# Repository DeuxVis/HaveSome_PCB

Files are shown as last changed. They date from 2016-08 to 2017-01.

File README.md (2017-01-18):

## Intro

This is a breakout board for low pin count SMD components : 0402 0603 0805 1206 SOT23 SOT223 SOT323.

Before that when you wanted to breadboard some SMD components it was a bit tricky :

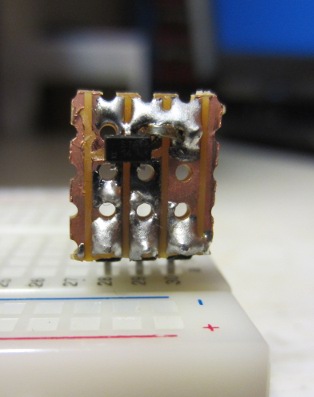
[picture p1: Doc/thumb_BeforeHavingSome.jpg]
Before Before having some...


Now you can use those tiny pretty easy to solder adapters :

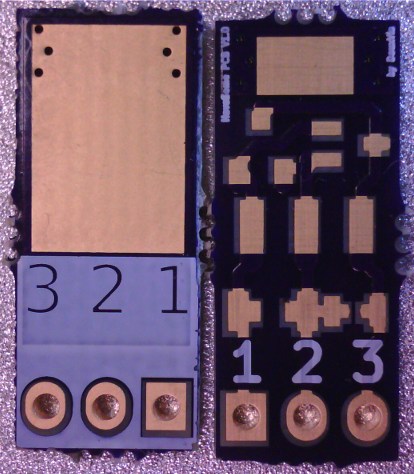
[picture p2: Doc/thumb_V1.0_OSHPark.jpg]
After Ready to prototype !


## Example uses

See some [sample usages](https://hackaday.io/project/10412-hacker-breakout-board-for-most-popular-smd#menu-details)

## Motivation

This breakout board is usefull to prototype with SMD components by allowing to plug those in a breadboard - or any matching 0.1" spaced pins, like some arduino family boards for instance.

It is derived from the [Awesome PCB project](https://hackaday.io/project/10412-hacker-breakout-board-for-most-popular-smd) by Simon.

My motivation for redesigning it from scratch was to :

*   Learn Kicad.
*   Allow people to order those boards for themselves, as Simon did not "yet" release his files.
*   I need to use some of those.

## Documentation

Not much yet, some pictures in the Doc subfolder.
You can probably use some informations in the [pdf from awesomepcb](http://www.awesomepcb.com/wp-content/uploads/2015/06/0603_0805_1206_SOT23_SOT223_0402_SOT323_rev01_documentation-PCB.pdf) although that board is somewhat different.

## Changelog

### V1.1

Status : still untested.

* Trying to let PCBs.io manufacturing process actually produce vias by not burying them under a pad.
* Beefier traces, especially on center pin - thanks to original Awsome PCB designer Simon for the suggestion on hackaday.io.
* Beefier vias for better current/heat transfer.
* Linked pad 2 and 4 of SOT223 for footprint compatible packages which lack the middle pin. 
* Added silkscreen annotations of pads to pins id matching - thanks to warhawk-avg on hackaday.io for the suggestion.

### V1.0

Status : tested and working but might be bugged depending on PCB manufacturer, vias between top and bottom heatsink surface may not be produced.

## License



This work is licensed under a [Creative Commons Attribution-NonCommercial-ShareAlike 3.0 Unported](https://creativecommons.org/licenses/by-nc-sa/3.0/) License - aka CC BY-NC-SA 3.0.

I chose non commercial because the idea is not mine and I don't want someone ripping off sales from [the original publisher](http://www.awesomepcb.com/product-category/pcb-bread-board-tools/).

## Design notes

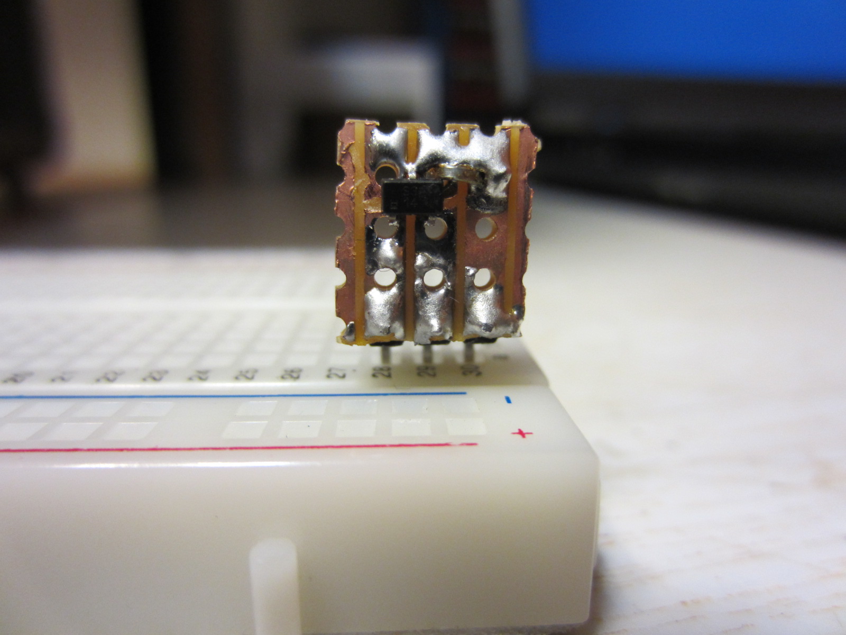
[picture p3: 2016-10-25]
Doc/BeforeHavingSome.jpg

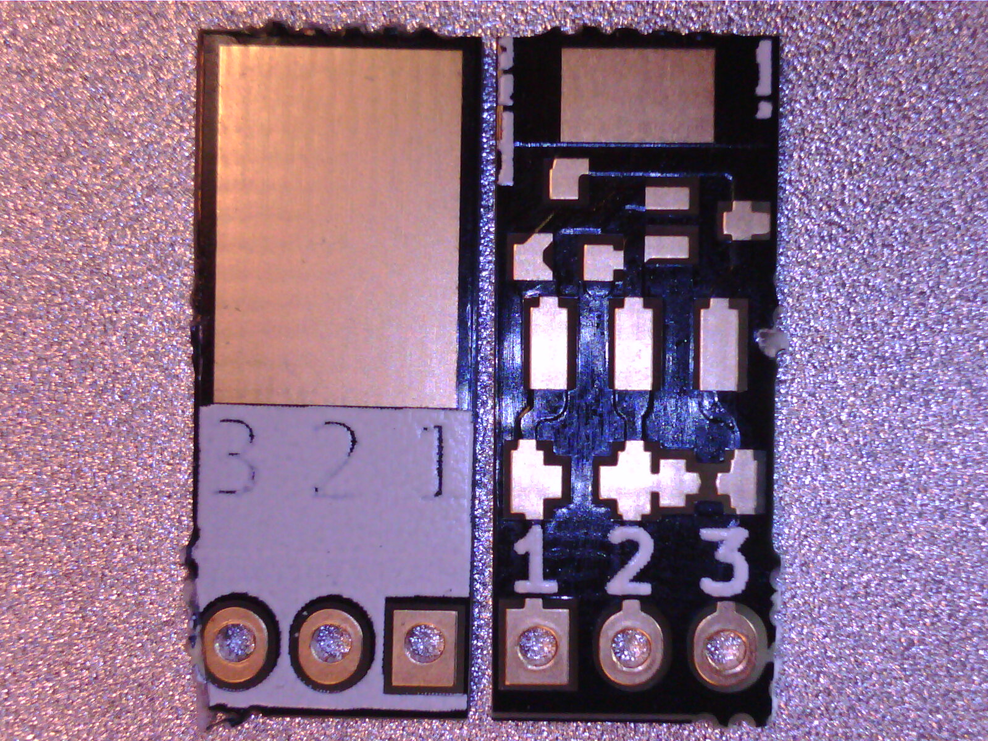
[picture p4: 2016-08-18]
Doc/V1.0_PCBs.io.jpg

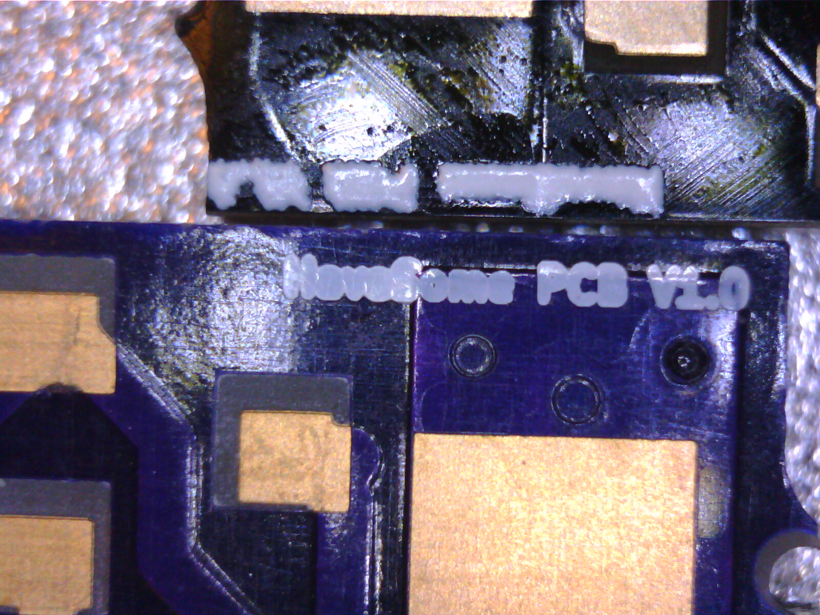
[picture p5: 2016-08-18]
Doc/V1.0_Comparizon_Silkscreen.jpg

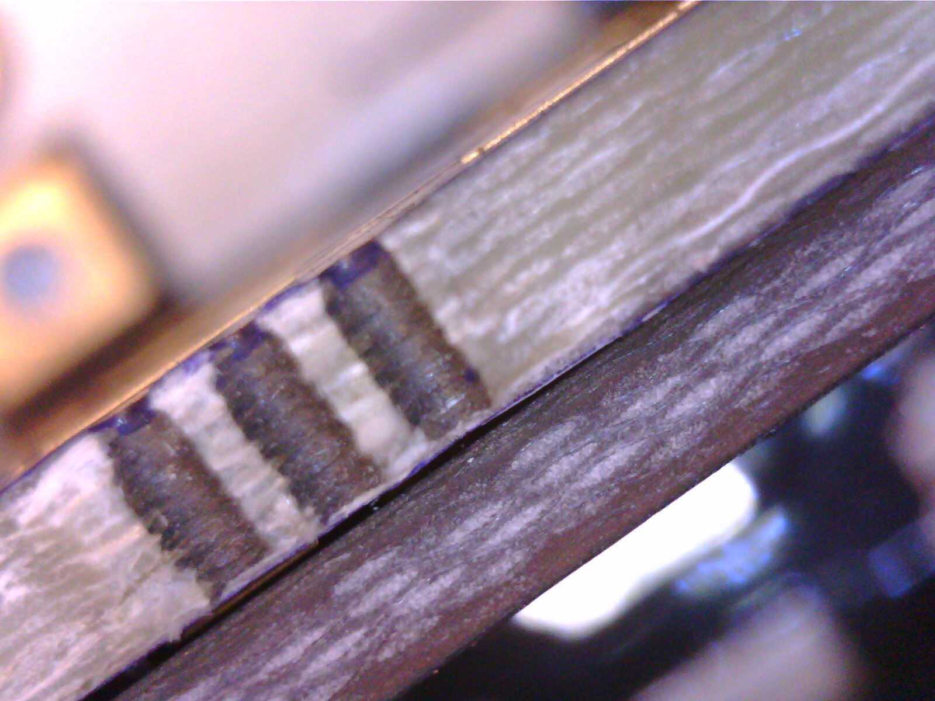
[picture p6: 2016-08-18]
Doc/V1.0_Comparizon_Thickness_OSHPark-bottom_PCBs.io-top.jpg

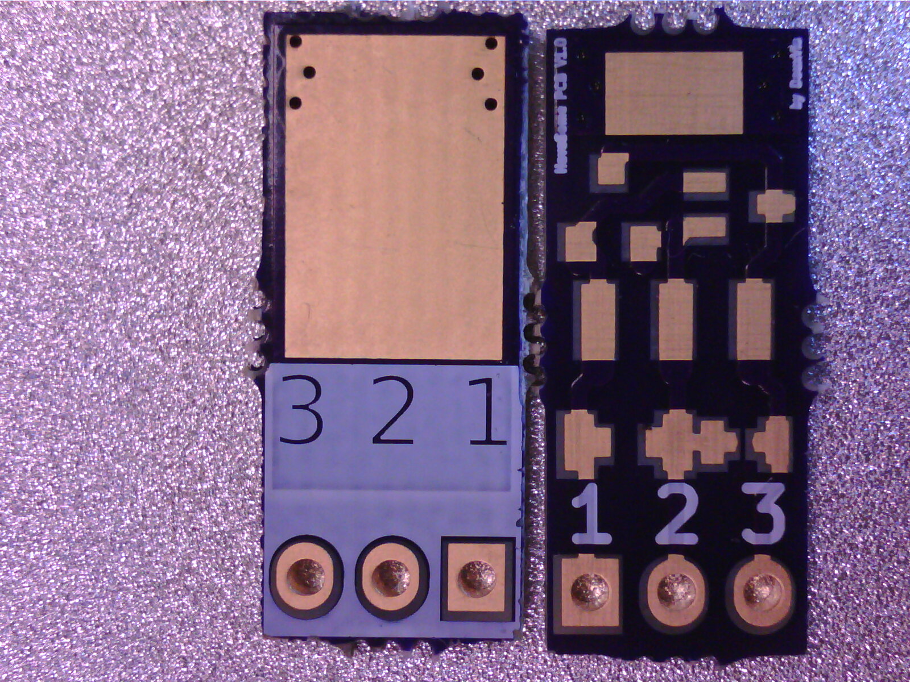
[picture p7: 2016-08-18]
Doc/V1.0_OSHPark.jpg

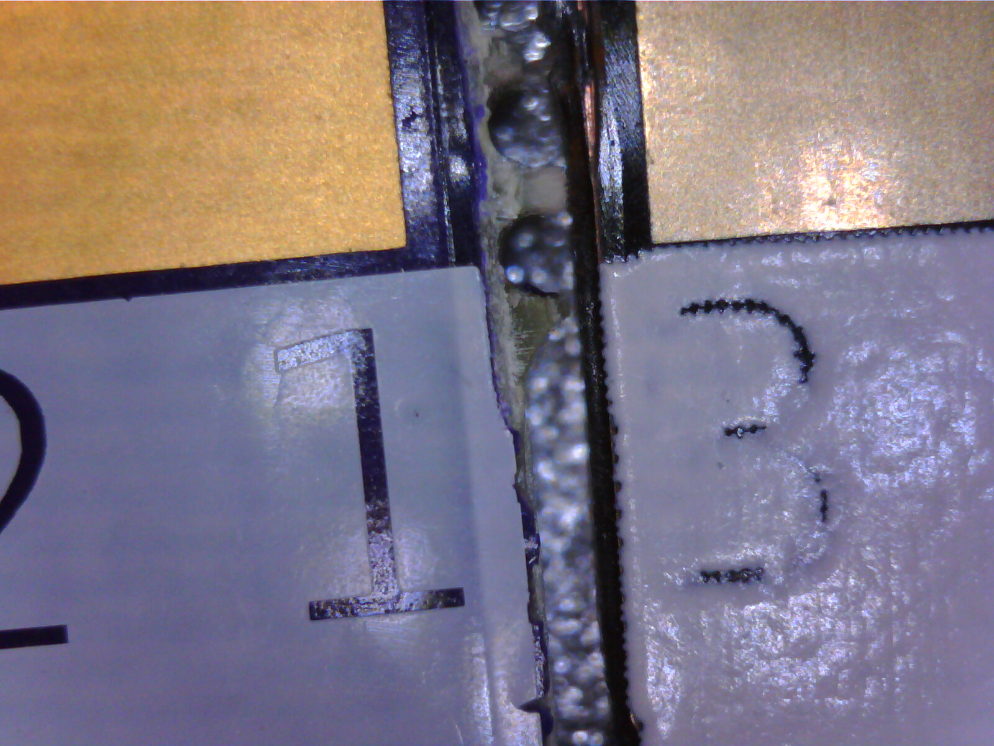
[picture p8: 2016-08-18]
Doc/V1.0_Comparizon_Negative_Silkscreen.jpg

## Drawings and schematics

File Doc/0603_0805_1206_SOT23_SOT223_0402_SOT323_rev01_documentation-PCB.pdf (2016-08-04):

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

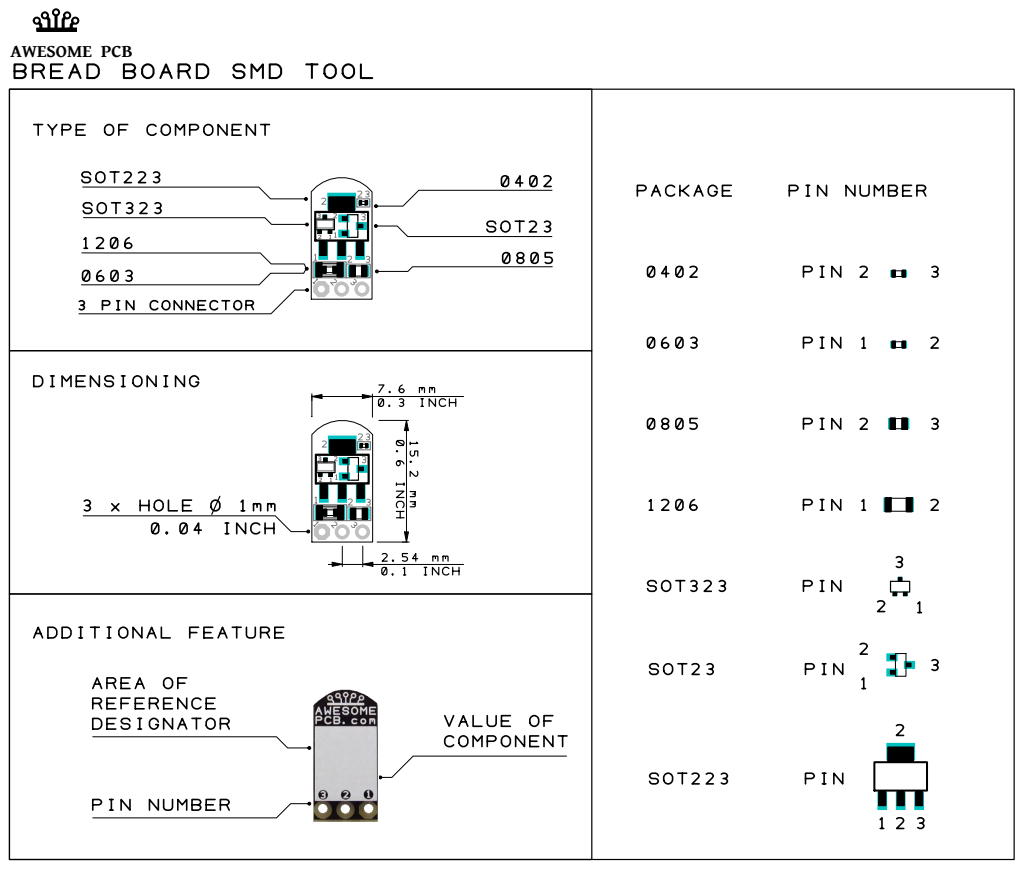
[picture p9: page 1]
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

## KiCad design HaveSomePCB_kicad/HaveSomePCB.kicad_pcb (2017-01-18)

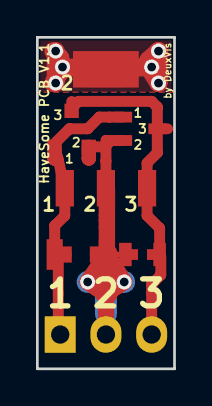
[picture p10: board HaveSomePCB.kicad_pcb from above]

Board: 2 copper layers, 7.6 x 18.4 mm, 8 parts (0 on the bottom side), 3 nets.

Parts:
PINS1: CONN_01X03; Pin_Header_Straight_1x03
SMD402: R0402; R_0402
SMD603: R0603; R_0603
SMD805: R0805; R_0805
SMD1206: R1206; R_1206
SOT23: APE8865NL-33-HF-3; SOT-23
SOT223: LD1117S33CTR; SOT-223
SOT323: BFR92; SOT-323

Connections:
unnamed: PINS1.1, SMD603.2, SMD1206.2, SOT23.1, SOT223.1, SOT323.1
unnamed: PINS1.2, SMD402.2, SMD603.1, SMD805.2, SMD1206.1, SOT23.2, SOT223.2, SOT223.4, SOT323.2
unnamed: PINS1.3, SMD402.1, SMD805.1, SOT23.3, SOT223.3, SOT323.3

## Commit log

2016-08-04 First import commit.
    [HaveSomePCB-B.Cu.gbl, HaveSomePCB-B.Mask.gbs, HaveSomePCB-B.SilkS.gbo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]
2016-08-18 Photos of the boards fabricated.
2017-01-18 Version 1.1 : - Trying to let PCBs.io manufacturing process actually produce vias by not burying them under a pad. - Beefier traces, especially on center pin - thanks to original Awsome PCB designer 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
    [HaveSomePCB-B.Cu.gbl, HaveSomePCB-B.Mask.gbs, HaveSomePCB-B.SilkS.gbo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]
2017-01-18 Removed duplicated file from gerbers zip.
